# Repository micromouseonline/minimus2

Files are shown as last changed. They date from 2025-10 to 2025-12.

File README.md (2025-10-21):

# MINIMUS-2
A half size micromouse design.

## Intent

Create hardware and software for a half-size micromouse robot. The design should be simple and easy to reproduce. It is not necessarily meant to compete at the highest levels. Rather, it should provide a working platform for beginners while still forming the basis for more performant derivatives.

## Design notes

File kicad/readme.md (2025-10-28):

# KiCAD design files for Minimus

All ECAD work is done wih KiCad V8.0

## Libraries

 - Add the JLCPCB parts library by following the instructions here:
    https://github.com/CDFER/JLCPCB-Kicad-Library

    This library contains all the basic parts avaiable from the JLCPCB assembly service, inclluding their footprints and part references.

    As far as I know, the library source is updated every day but the local copy is not so all parts should be checked at the time of a request for manufacture.

    Updates can be done manually from the Plugin manager.

    Since the library is a git repository, it might be possible to clone or fork it, create a local branch and edit the footprints that way.

 - There will also be a custom project library for the parts used in minimus.

## Plugins

 - Add the KiCAD JLC PCB Tools by following the instructions here
     https://github.com/Bouni/kicad-jlcpcb-tools

## Schematic Style

Note that the symbols used by the JLCPCB parts library do not match the symbols that are the default in KiCAD supplied libraries. The most important attributes are all those relating specifically to the JLCPCB part - size, part number, type and so on. If the symbols are a problem, it might be best to copy each part from the JLCPCB library to the project library and edit the symbol there.

## PCB Style

For a half-size mouse, all the components are small and contained in a small PCB. It is not practical to have the component reference and value for all parts. If the boards are to be manufacured by a service, this is not a great problem. A reference diagram showing the part placement from the FAB layers would be helpful for testing and debugging.

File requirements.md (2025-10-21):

# MINIMUS-2
A half size micromouse design.

## Intent

Create hardware and software for a half-size micromouse robot. The design should be simple and easy to reproduce. It is not necessarily meant to compete at the highest levels. Rather, it should provide a working platform for beginners while still forming the basis for more performant derivatives.

As with many of my projects, a key aim is to lay the foundation for a competitive robot in the future and so there seems little point in overly constraining the design.

### Mechanical

 1. The chassis will be based on the PCB which will be 0.8mm FR4. 
 1. Dimensions should not exceed 50mm x 40mm.
 1. Motor mounts will be 3D printed. Ideally using SLA (resin) techniques though FDM should be an option.
 1. The differential drive will be by means of two wheels to leave space for a suction fan
 1. The initial design will not incorporate a fan but allowance should be made at all times for the possibility of adding a fan at a later date.
 1. Motors will be commonly available 6x12mm coreless types.
 1. Gears are readily available as 8+54 tooth 0.3mod pairs intended for small drones. That leaves the wheels larger than ideal (> 18mm diameter). A tradeoff for availability.
 1. Wheels will need to be SLA printed to engage with available drive gears.
 1. Tyres could be deNano types but o-rings or similar are likely to prove suitable at this stage.

### Sensors

 1. Wall sensors will use four pairs of IR or visible light reflective devices. Emitters may need to be 5mm diameter though 3mm types are to be preferred. Narrow beam emitters are coupled with detectors having a wider acceptance angle.  These whould be as simple as possible.
 1. An IMU having at least 6 axes (3*gyro + 3*accel) will provide feedback for rotational motion. The accelerometers may prove necessary for velocity estimation, crash detection and user input.
 1. Wheel encoders are the promary inputs for linear odometry and also make useful user input devices. High resolution magentic angle sensors may be fitted to the main wheels with the sensor carriers vertical on the PCB behind the motor mounts. Magnetic shielding for the motors may be needed. Lower resolution encoders 1. possibly optical 1. may be effective if used with the IMU.
  
### User IO

 1. There should be at least one user button in addition to the processor reset. This button may also be used to place the processor into bootloader mode at power up if necessary/appropriate. The ESP32 processor are likely to need this.
 1. All otherwise unused pins should have LEDs attached for state and/or operating mode indication. Neopixel devices are useful if there is support available. If space permits, an I2C LED driver might be an option.
 1. Debug (SWD) and serial connections are essential during development. These must be reliable but have low insertion force and relatively long cycle life.
 1. A small buzzer is often useful if space permits.
 1. A pluggable display would be a great addition. Conceivably it could be a pass-through for the debug/programming connector.
 1. A radio link might be substituted for a display. Perhaps all these could be stacked for development and removed for contest runs.

### Electrical

 1. Power should come from 1 or 2 LiPo cells. A single cell might be sufficient but it is best to allow for more in the design. Space must be left for two cells in the mechanical layout.
 1. Care must be taken to find suitable cells that are likely to have a long availability.
 1. Cells should have individual connectors for greatest flexibility.
 1. Connectors are likely to need modification for low insertion force as cycle life is often low.
 1. Try to find commonly used connectors such as those used in micro drones. These are very fiddly to make by hand. Prefer ready-made.
 1. Run times can be long so cell capacity will need careful consideration.
 1. Power switching will need a mechanical switch and high-side MOSFET as suitably sized switches do not have sufficient current carrying capacity.

### Processor

 1. A 32 bit processor seems inevitable. It should run C++ code and, for those who must, MicroPython.
 1. Emphasis should be given to maximising available RAM and the availability of non-volatile storage. 
 1. Flash sizes should exceed 512K for flexibility.
 1. At least one SPI and one I2C peripheral will be needed to accomodate the IMU
 1. Ideally, two hardware quadrature input channels will be available or should be possible using interrupts. If the same pins can be used for SPI, in addition to the IMU, then that would provide greater flexibility in the choice of encoder topology. Note that some optical encoder designs might need analogue inputs.
 1. There should be a suitable debug interface that will work with commonly available tools like openOCD.
 1. For power saving, it should be possible to activate a low power or standby mode. This may be as simple as reducing the processor clock.
 1. It would be most convenient, for C+++ development, if the processor is supported by PlatformIO. Like it or not, this provides a great deal of flexibility. Not least in the choice of available development environments across platforms.
 1. Support for the Arduino framework, while not giving the highest performance, would greatly simplify the portability of the code.
 1. Early adoption of an RTOS might bring benefits. It is automatically available for the ESP32 and easy to implement for the STM32
 1. Processor choice seems likely to be between STM32F413 and ESP32. Both provide all the required features. Ready built breakout boards are unusally rare in this size. STM32F413RGT and ESP32-PICO placed directly on the board are the most space efficient. ESP32 modules can be compact and provide wireless links but are still quite large and may mean a dual board configuration. Of course, with care, the entire processor could be on a (probably custom) carrier.
  
### Assembly

 1. Given the size of the robot, it is going to require SMT devices. Some of these are hard to mount without some experience. IMUs and motor drivers in particular are usually tiny, leadless devices. It should be assumed that boards will be pre-assembled by services such as PCBWAY or JLCPCB. The higher cost is likely to be easily offset by improved reliability, reduced frustration and the removal of a requirement to hold stocks of components locally.
 2. A pre-assembled board should maximise the cost benefits by having as much circuitry as possible mounted at manufacture. That includes encoders and, if appropriate, sensor carriers with all but the optical devices already mounted. 
 3. It may be a good idea to include chargers and/or serial interface options at the same time.
 4. Groups purchases are probably the way to go.
 5. Fasteners must be readily avaiable and robust.
 6. Bearings, axles and retainers can be a challenge. All must be readily available with little or no modification. For example, axle shafts will ideally be available in the right length without cutting. Good push fits can be surprisingly effective at these scales.

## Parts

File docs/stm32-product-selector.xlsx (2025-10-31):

Microcontrollers & microprocessors/STM32 32-bit Arm Cortex MCUs
Part Number | General Description | Marketing Status | USART typ | UART Total | UART typ | Timers (32-bit) typ | Timers (16-bit) typ | SPI Total | SPI typ | Package Pin Count | I2C Total | I2C typ | FPU | Data E2PROM (B) nom | CCM RAM (I/D) (kByte) typ | Advanced Motor Control Timers | Additional Interfaces | A/D Converters 16-bit |  | A/D Converters 14-bit | A/D Converters 12-bit | A/D Converters 14-bit | A/D Converters 12-bit | Package | Core | Operating Frequency (MHz) | Flash Size (kB) (Prog) | RAM Size (kB) | I/Os (High Current) | GP Timers Total | A/D Converters: Total Number of A/D Converters
 |  |  |  |  |  |  |  |  |  |  |  |  |  |  |  |  |  | Number of Channels typ | Number of A/D Converters typ | Number of Channels typ | Number of Channels typ | Number of A/D Converters typ | Number of A/D Converters typ
STM32L4Q5RGT6P (https://www.st.com/en/product/stm32l4q5rgt6p.html) | Ultra-low-power with FPU Arm Cortex-M4 MCU 120 MHz with 1024 kbytes of Flash memory, USB OTG, DFSDM, CHROM-ART, AES, PKA | Active | - | 1 | - | 2 | 11 | - | - | 64 | 4 | 4 | Single-precision FPU | - | - | - | DFSDM, SAI | - | - | - | - | - | 2 | LQFP 64 10x10x1.4 mm | Arm Cortex-M4 | 120 | 1024 | 320 | - | 13 | 2
STM32L4Q5RGT3 (https://www.st.com/en/product/stm32l4q5rgt3.html) | Ultra-low-power with FPU Arm Cortex-M4 MCU 120 MHz with 1024 kbytes of Flash memory, USB OTG, DFSDM, CHROM-ART, AES, PKA | Active | 6 | 7 | - | 2 | 11 | 9 | 3 | 64 | 4 | 4 | Single-precision FPU | - | - | - | DFSDM, SAI | - | - | - | 16 | - | 2 | LQFP 64 10x10x1.4 mm | Arm Cortex-M4 | 120 | 1024 | 320 | 54 | 13 | 2
STM32L4Q5RGT6 (https://www.st.com/en/product/stm32l4q5rgt6.html) | Ultra-low-power with FPU Arm Cortex-M4 MCU 120 MHz with 1024 kbytes of Flash memory, USB OTG, DFSDM, CHROM-ART, AES, PKA | Active | 6 | 7 | - | 2 | 11 | 9 | 3 | 64 | 4 | 4 | Single-precision FPU | - | - | - | DFSDM, SAI | - | - | - | 16 | - | 2 | LQFP 64 10x10x1.4 mm | Arm Cortex-M4 | 120 | 1024 | 320 | 54 | 13 | 2
STM32L4P5RGT6 (https://www.st.com/en/product/stm32l4p5rgt6.html) | Ultra-low-power with FPU Arm Cortex-M4 MCU 120 MHz with 1024 kbytes of Flash memory, USB OTG, DFSDM, CHROM-ART | Active | - | 1 | - | 2 | 11 | - | - | 64 | 4 | 4 | Single-precision FPU | - | - | - | DFSDM, SAI | - | - | - | - | - | 2 | LQFP 64 10x10x1.4 mm | Arm Cortex-M4 | 120 | 1024 | 320 | 54 | 13 | 2
STM32L4P5RGT6P (https://www.st.com/en/product/stm32l4p5rgt6p.html) | Ultra-low-power with FPU Arm Cortex-M4 MCU 120 MHz with 1024 kbytes of Flash memory, USB OTG, DFSDM, CHROM-ART | Active | - | 1 | - | 2 | 11 | - | - | 64 | 4 | 4 | Single-precision FPU | - | - | - | DFSDM, SAI | - | - | - | - | - | 2 | LQFP 64 10x10x1.4 mm | Arm Cortex-M4 | 120 | 1024 | 320 | 54 | 13 | 2
STM32U595RIT6QTR (https://www.st.com/en/product/stm32u595rit6qtr.html) | Ultra-low-power with FPU Arm Cortex-M33 MCU with TrustZone, 160 MHz with 2 Mbytes of Flash memory | Active | 4 | 8 | 3 | 4 | 11 | 7 | 3 | 64 | 6 | 6 | Single-precision FPU | - | - | - | - | - | - | 15 | 15 | 2 | 1 | LQFP 64 10x10x1.4 mm | Arm Cortex-M33 | 160 | 2048 | 2514 | 47 | 15 | 3
STM32U595RIT6Q (https://www.st.com/en/product/stm32u595rit6q.html) | Ultra-low-power with FPU Arm Cortex-M33 MCU with TrustZone, 160 MHz with 2 Mbytes of Flash memory | Active | 4 | 8 | 3 | 4 | 11 | 7 | 3 | 64 | 6 | 6 | Single-precision FPU | - | - | - | - | - | - | 15 | 15 | 2 | 1 | LQFP 64 10x10x1.4 mm | Arm Cortex-M33 | 160 | 2048 | 2514 | 47 | 15 | 3
STM32U595RIT6TR (https://www.st.com/en/product/stm32u595rit6tr.html) | Ultra-low-power with FPU Arm Cortex-M33 MCU with TrustZone, 160 MHz with 2 Mbytes of Flash memory | Active | 4 | 8 | 3 | 4 | 11 | 7 | 3 | 64 | 6 | 6 | Single-precision FPU | - | - | - | - | - | - | 17 | 17 | 2 | 1 | LQFP 64 10x10x1.4 mm | Arm Cortex-M33 | 160 | 2048 | 2514 | 51 | 15 | 3
STM32U595RIT6 (https://www.st.com/en/product/stm32u595rit6.html) | Ultra-low-power with FPU Arm Cortex-M33 MCU with TrustZone, 160 MHz with 2 Mbytes of Flash memory | Active | 4 | 8 | 3 | 4 | 11 | 7 | 3 | 64 | 6 | 6 | Single-precision FPU | - | - | - | - | - | - | 17 | 17 | 2 | 1 | LQFP 64 10x10x1.4 mm | Arm Cortex-M33 | 160 | 2048 | 2514 | 51 | 15 | 3
STM32U595RJT6 (https://www.st.com/en/product/stm32u595rjt6.html) | Ultra-low-power with FPU Arm Cortex-M33 MCU with TrustZone, 160 MHz with 4 Mbytes of Flash memory | Active | 4 | 8 | 3 | 4 | 11 | 7 | 3 | 64 | 6 | 6 | Single-precision FPU | - | - | - | - | - | - | 17 | 17 | 2 | 1 | LQFP 64 10x10x1.4 mm | Arm Cortex-M33 | 160 | 4096 | 2514 | 51 | 15 | 3
STM32U595RJT3 (https://www.st.com/en/product/stm32u595rjt3.html) | Ultra-low-power with FPU Arm Cortex-M33 MCU with TrustZone, 160 MHz with 4 Mbytes of Flash memory | Active | 4 | 8 | 3 | 4 | 11 | 7 | 3 | 64 | 6 | 6 | Single-precision FPU | - | - | - | - | - | - | 17 | 17 | 2 | 1 | LQFP 64 10x10x1.4 mm | Arm Cortex-M33 | 160 | 4096 | 2514 | 51 | 15 | 3
STM32U595RJT6Q (https://www.st.com/en/product/stm32u595rjt6q.html) | Ultra-low-power with FPU Arm Cortex-M33 MCU with TrustZone, 160 MHz with 4 Mbytes of Flash memory | Active | 4 | 8 | 3 | 4 | 11 | 7 | 3 | 64 | 6 | 6 | Single-precision FPU | - | - | - | - | - | - | 15 | 15 | 2 | 1 | LQFP 64 10x10x1.4 mm | Arm Cortex-M33 | 160 | 4096 | 2514 | 47 | 15 | 3
STM32U5A5RJT6 (https://www.st.com/en/product/stm32u5a5rjt6.html) | Ultra-low-power with FPU Arm Cortex-M33 MCU with TrustZone, 160 MHz with 4 Mbytes of Flash memory | Active | 4 | 8 | 3 | 4 | 11 | 7 | 3 | 64 | 6 | 6 | Single-precision FPU | - | - | - | - | - | - | 17 | 17 | 2 | 1 | LQFP 64 10x10x1.4 mm | Arm Cortex-M33 | 160 | 4096 | 2514 | 51 | 15 | 3
STM32U5A5RJT6Q (https://www.st.com/en/product/stm32u5a5rjt6q.html) | Ultra-low-power with FPU Arm Cortex-M33 MCU with TrustZone, 160 MHz with 4 Mbytes of Flash memory | Active | 4 | 8 | 3 | 4 | 11 | 7 | 3 | 64 | 6 | 6 | Single-precision FPU | - | - | - | - | - | - | 15 | 15 | 2 | 1 | LQFP 64 10x10x1.4 mm | Arm Cortex-M33 | 160 | 4096 | 2514 | 47 | 15 | 3
STM32U575RGT6TR (https://www.st.com/en/product/stm32u575rgt6tr.html) | Ultra-low-power with FPU Arm Cortex-M33 MCU with TrustZone, 160 MHz with 1 Mbyte of Flash memory | Active | 3 | 6 | 2 | - | - | 6 | 3 | 64 | 4 | 4 | Single-precision FPU | - | - | - | ADF, MDF, Parallel camera interface, SAI, SD/MMC, Vref Buffer | - | - | 17 | 17 | 1 | 1 | LQFP 64 10x10x1.4 mm | Arm Cortex-M33 | 160 | 1024 | 786 | 50 | - | 2
STM32U575RGT6QTR (https://www.st.com/en/product/stm32u575rgt6qtr.html) | Ultra-low-power with FPU Arm Cortex-M33 MCU with TrustZone, 160 MHz with 1 Mbyte of Flash memory | Active | 3 | 6 | 2 | - | - | 6 | 3 | 64 | 4 | 4 | Single-precision FPU | - | - | - | ADF, MDF, Parallel camera interface, SAI, SD/MMC, Vref Buffer | - | - | 15 | 15 | 1 | 1 | LQFP 64 10x10x1.4 mm | Arm Cortex-M33 | 160 | 1024 | 786 | 47 | - | 2
STM32U575RGT3 (https://www.st.com/en/product/stm32u575rgt3.html) | Ultra-low-power with FPU Arm Cortex-M33 MCU with TrustZone, 160 MHz with 1 Mbyte of Flash memory | Active | 3 | 6 | 2 | - | - | 6 | 3 | 64 | 4 | 4 | Single-precision FPU | - | - | - | ADF, MDF, Parallel camera interface, SAI, SD/MMC, Vref Buffer | - | - | 17 | 17 | 1 | 1 | LQFP 64 10x10x1.4 mm | Arm Cortex-M33 | 160 | 1024 | 786 | 50 | - | 2
STM32U575RGT6 (https://www.st.com/en/product/stm32u575rgt6.html) | Ultra-low-power with FPU Arm Cortex-M33 MCU with TrustZone, 160 MHz with 1 Mbyte of Flash memory | Active | 3 | 6 | 2 | - | - | 6 | 3 | 64 | 4 | 4 | Single-precision FPU | - | - | - | ADF, MDF, Parallel camera interface, SAI, SD/MMC, Vref Buffer | - | - | 17 | 17 | 1 | 1 | LQFP 64 10x10x1.4 mm | Arm Cortex-M33 | 160 | 1024 | 786 | 50 | - | 2
STM32U575RGT6Q (https://www.st.com/en/product/stm32u575rgt6q.html) | Ultra-low-power with FPU Arm Cortex-M33 MCU with TrustZone, 160 MHz with 1 Mbyte of Flash memory | Active | 3 | 6 | 2 | - | - | 6 | 3 | 64 | 4 | 4 | Single-precision FPU | - | - | - | ADF, MDF, Parallel camera interface, SAI, SD/MMC, Vref Buffer | - | - | 15 | 15 | 1 | 1 | LQFP 64 10x10x1.4 mm | Arm Cortex-M33 | 160 | 1024 | 786 | 47 | - | 2
STM32U575RIT3 (https://www.st.com/en/product/stm32u575rit3.html) | Ultra-low-power with FPU Arm Cortex-M33 MCU with TrustZone, 160 MHz with 2 Mbytes of Flash memory | Active | 3 | 6 | 2 | - | - | 6 | 3 | 64 | 4 | 4 | Single-precision FPU | - | - | - | ADF, MDF, Parallel camera interface, SAI, SD/MMC | - | - | 17 | 17 | 1 | 1 | LQFP 64 10x10x1.4 mm | Arm Cortex-M33 | 160 | 2048 | 786 | 50 | - | 2
STM32U575RIT6Q (https://www.st.com/en/product/stm32u575rit6q.html) | Ultra-low-power with FPU Arm Cortex-M33 MCU with TrustZone, 160 MHz with 2 Mbytes of Flash memory | Active | 3 | 6 | 2 | - | - | 6 | 3 | 64 | 4 | 4 | Single-precision FPU | - | - | - | ADF, MDF, Parallel camera interface, SAI, SD/MMC | - | - | 15 | 15 | 1 | 1 | LQFP 64 10x10x1.4 mm | Arm Cortex-M33 | 160 | 2048 | 786 | 47 | - | 2
STM32U575RIT6 (https://www.st.com/en/product/stm32u575rit6.html) | Ultra-low-power with FPU Arm Cortex-M33 MCU with TrustZone, 160 MHz with 2 Mbytes of Flash memory | Active | 3 | 6 | 2 | - | - | 6 | 3 | 64 | 4 | 4 | Single-precision FPU | - | - | - | ADF, MDF, Parallel camera interface, SAI, SD/MMC | - | - | 17 | 17 | 1 | 1 | LQFP 64 10x10x1.4 mm | Arm Cortex-M33 | 160 | 2048 | 786 | 50 | - | 2
STM32U585RIT3TR (https://www.st.com/en/product/stm32u585rit3tr.html) | Ultra-low-power with FPU Arm Cortex-M33 MCU with TrustZone, 160 MHz with 2 Mbytes of Flash memory | Active | 3 | 6 | 2 | - | - | 6 | 3 | 64 | 4 | 4 | Single-precision FPU | - | - | - | ADF, MDF, Parallel camera interface, SAI, SD/MMC | - | - | 17 | 17 | 1 | 1 | LQFP 64 10x10x1.4 mm | Arm Cortex-M33 | 160 | 2048 | 786 | 50 | - | 2
STM32U585RIT6 (https://www.st.com/en/product/stm32u585rit6.html) | Ultra-low-power with FPU Arm Cortex-M33 MCU with TrustZone, 160 MHz with 2 Mbytes of Flash memory | Active | 3 | 6 | 2 | - | - | 6 | 3 | 64 | 4 | 4 | Single-precision FPU | - | - | - | ADF, MDF, Parallel camera interface, SAI, SD/MMC | - | - | 17 | 17 | 1 | 1 | LQFP 64 10x10x1.4 mm | Arm Cortex-M33 | 160 | 2048 | 786 | 50 | - | 2
STM32U585RIT6QTR (https://www.st.com/en/product/stm32u585rit6qtr.html) | Ultra-low-power with FPU Arm Cortex-M33 MCU with TrustZone, 160 MHz with 2 Mbytes of Flash memory | Active | 3 | 6 | 2 | - | - | 6 | 3 | 64 | 4 | 4 | Single-precision FPU | - | - | - | ADF, MDF, Parallel camera interface, SAI, SD/MMC | - | - | 15 | 15 | 1 | 1 | LQFP 64 10x10x1.4 mm | Arm Cortex-M33 | 160 | 2048 | 786 | 47 | - | 2
STM32U585RIT6Q (https://www.st.com/en/product/stm32u585rit6q.html) | Ultra-low-power with FPU Arm Cortex-M33 MCU with TrustZone, 160 MHz with 2 Mbytes of Flash memory | Active | 3 | 6 | 2 | - | - | 6 | 3 | 64 | 4 | 4 | Single-precision FPU | - | - | - | ADF, MDF, Parallel camera interface, SAI, SD/MMC | - | - | 15 | 15 | 1 | 1 | LQFP 64 10x10x1.4 mm | Arm Cortex-M33 | 160 | 2048 | 786 | 47 | - | 2
STM32U585RIT6TR (https://www.st.com/en/product/stm32u585rit6tr.html) | Ultra-low-power with FPU Arm Cortex-M33 MCU with TrustZone, 160 MHz with 2 Mbytes of Flash memory | Active | 3 | 6 | 2 | - | - | 6 | 3 | 64 | 4 | 4 | Single-precision FPU | - | - | - | ADF, MDF, Parallel camera interface, SAI, SD/MMC | - | - | 17 | 17 | 1 | 1 | LQFP 64 10x10x1.4 mm | Arm Cortex-M33 | 160 | 2048 | 786 | 50 | - | 2
STM32U585RIT3Q (https://www.st.com/en/product/stm32u585rit3q.html) | Ultra-low-power with FPU Arm Cortex-M33 MCU with TrustZone, 160 MHz with 2 Mbytes of Flash memory | Active | 3 | 6 | 2 | 4 | 11 | 6 | 3 | 64 | 4 | 4 | Single-precision FPU | - | - | 2 | ADF, MDF, Parallel camera interface, SAI, SD/MMC | - | - | 15 | 15 | 1 | 1 | LQFP 64 10x10x1.4 mm | Arm Cortex-M33 | 160 | 2048 | 786 | 47 | 15 | 2
STM32U585RIT3 (https://www.st.com/en/product/stm32u585rit3.html) | Ultra-low-power with FPU Arm Cortex-M33 MCU with TrustZone, 160 MHz with 2 Mbytes of Flash memory | Active | 3 | 6 | 2 | - | - | 6 | 3 | 64 | 4 | 4 | Single-precision FPU | - | - | - | ADF, MDF, Parallel camera interface, SAI, SD/MMC | - | - | 17 | 17 | 1 | 1 | LQFP 64 10x10x1.4 mm | Arm Cortex-M33 | 160 | 2048 | 786 | 50 | - | 2
STM32L4A6RGT6P (https://www.st.com/en/product/stm32l4a6rgt6p.html) | Ultra-low-power with FPU Arm Cortex-M4 MCU 80 MHz with 1 Mbyte of Flash memory, USB OTG, LCD, AES-256, DFSDM | Active | 3 | 6 | 2 | 2 | 9 | 6 | 3 | 64 | 3 | 3 | Single-precision FPU | - | - | - | DFSDM, Parallel camera interface, SAI, SD/MMC | - | - | - | 15 | - | 3 | LQFP 64 10x10x1.4 mm | Arm Cortex-M4 | 80 | 1024 | 320 | 50 | 11 | 3
STM32L4A6RGT6TR (https://www.st.com/en/product/stm32l4a6rgt6tr.html) | Ultra-low-power with FPU Arm Cortex-M4 MCU 80 MHz with 1 Mbyte of Flash memory, USB OTG, LCD, AES-256, DFSDM | Active | 3 | 6 | 2 | 2 | 9 | 6 | 3 | 64 | 3 | 3 | Single-precision FPU | - | - | - | DFSDM, Parallel camera interface, SAI, SD/MMC | - | - | - | 16 | - | 3 | LQFP 64 10x10x1.4 mm | Arm Cortex-M4 | 80 | 1024 | 320 | 52 | 11 | 3
STM32L4A6RGT7 (https://www.st.com/en/product/stm32l4a6rgt7.html) | Ultra-low-power with FPU Arm Cortex-M4 MCU 80 MHz with 1 Mbyte of Flash memory, USB OTG, LCD, AES-256, DFSDM | Active | 3 | 6 | 2 | 2 | 9 | 6 | 3 | 64 | 3 | 3 | Single-precision FPU | - | - | - | DFSDM, Parallel camera interface, SAI, SD/MMC | - | - | - | 16 | - | 3 | LQFP 64 10x10x1.4 mm | Arm Cortex-M4 | 80 | 1024 | 320 | 52 | 11 | 3
STM32L4A6RGT6 (https://www.st.com/en/product/stm32l4a6rgt6.html) | Ultra-low-power with FPU Arm Cortex-M4 MCU 80 MHz with 1 Mbyte of Flash memory, USB OTG, LCD, AES-256, DFSDM | Active | 3 | 6 | 2 | 2 | 9 | 6 | 3 | 64 | 3 | 3 | Single-precision FPU | - | - | - | DFSDM, Parallel camera interface, SAI, SD/MMC | - | - | - | 16 | - | 3 | LQFP 64 10x10x1.4 mm | Arm Cortex-M4 | 80 | 1024 | 320 | 52 | 11 | 3
STM32L4A6RGT7TR (https://www.st.com/en/product/stm32l4a6rgt7tr.html) | Ultra-low-power with FPU Arm Cortex-M4 MCU 80 MHz with 1 Mbyte of Flash memory, USB OTG, LCD, AES-256, DFSDM | Active | 3 | 6 | 2 | 2 | 9 | 6 | 3 | 64 | 3 | 3 | Single-precision FPU | - | - | - | DFSDM, Parallel camera interface, SAI, SD/MMC | - | - | - | 16 | - | 3 | LQFP 64 10x10x1.4 mm | Arm Cortex-M4 | 80 | 1024 | 320 | 52 | 11 | 3
STM32L496RGT6TR (https://www.st.com/en/product/stm32l496rgt6tr.html) | Ultra-low-power with FPU Arm Cortex-M4 MCU 80 MHz with 1 Mbyte of Flash memory, USB OTG, LCD, DFSDM | Active | 3 | 6 | 2 | 2 | 9 | 6 | 3 | 64 | - | - | Single-precision FPU | - | - | - | DFSDM, Parallel camera interface, SAI, SD/MMC | - | - | - | 16 | - | 3 | LQFP 64 10x10x1.4 mm | Arm Cortex-M4 | 80 | 1024 | 320 | 52 | 11 | 3
STM32L496RGT3 (https://www.st.com/en/product/stm32l496rgt3.html) | Ultra-low-power with FPU Arm Cortex-M4 MCU 80 MHz with 1 Mbyte of Flash memory, USB OTG, LCD, DFSDM | Active | 3 | 6 | 2 | 2 | 9 | 6 | 3 | 64 | - | - | Single-precision FPU | - | - | - | DFSDM, Parallel camera interface, SAI, SD/MMC | - | - | - | 16 | - | 3 | LQFP 64 10x10x1.4 mm | Arm Cortex-M4 | 80 | 1024 | 320 | 52 | 11 | 3
STM32L496RGT6P (https://www.st.com/en/product/stm32l496rgt6p.html) | Ultra-low-power with FPU Arm Cortex-M4 MCU 80 MHz with 1 Mbyte of Flash memory, USB OTG, LCD, DFSDM | Active | 3 | 6 | 2 | 2 | 9 | 6 | 3 | 64 | - | - | Single-precision FPU | - | - | - | DFSDM, Parallel camera interface, SAI, SD/MMC | - | - | - | 15 | - | 3 | LQFP 64 10x10x1.4 mm | Arm Cortex-M4 | 80 | 1024 | 320 | 50 | 11 | 3
STM32L496RGT3TR (https://www.st.com/en/product/stm32l496rgt3tr.html) | Ultra-low-power with FPU Arm Cortex-M4 MCU 80 MHz with 1 Mbyte of Flash memory, USB OTG, LCD, DFSDM | Active | 3 | 6 | 2 | 2 | 9 | 6 | 3 | 64 | - | - | Single-precision FPU | - | - | - | DFSDM, Parallel camera interface, SAI, SD/MMC | - | - | - | 16 | - | 3 | LQFP 64 10x10x1.4 mm | Arm Cortex-M4 | 80 | 1024 | 320 | 52 | 11 | 3
STM32L496RGT6 (https://www.st.com/en/product/stm32l496rgt6.html) | Ultra-low-power with FPU Arm Cortex-M4 MCU 80 MHz with 1 Mbyte of Flash memory, USB OTG, LCD, DFSDM | Active | 3 | 6 | 2 | 2 | 9 | 6 | 3 | 64 | - | - | Single-precision FPU | - | - | - | DFSDM, Parallel camera interface, SAI, SD/MMC | - | - | - | 16 | - | 3 | LQFP 64 10x10x1.4 mm | Arm Cortex-M4 | 80 | 1024 | 320 | 52 | 11 | 3
STM32F423RHT6TR (https://www.st.com/en/product/stm32f423rht6tr.html) | High-performance access line, Arm Cortex-M4 core with DSP and FPU, 1, 5 MByte of Flash memory, 100 MHz CPU, ART Accelerator, DFSDM, AES | Active | 4 | 7 | 3 | 2 | 12 | 9 | 5 | 64 | 4 | 3 | - | - | - | - | DFSDM, SAI, SD/MMC | - | - | - | 16 | - | 1 | LQFP 64 10x10x1.4 mm | Arm Cortex-M4 | 100 | 1536 | 320 | 50 | 14 | 1
STM32F423RHT6 (https://www.st.com/en/product/stm32f423rht6.html) | High-performance access line, Arm Cortex-M4 core with DSP and FPU, 1, 5 MByte of Flash memory, 100 MHz CPU, ART Accelerator, DFSDM, AES | Active | 4 | 7 | 3 | 2 | 12 | 9 | 5 | 64 | 4 | 3 | - | - | - | - | DFSDM, SAI, SD/MMC | - | - | - | 16 | - | 1 | LQFP 64 10x10x1.4 mm | Arm Cortex-M4 | 100 | 1536 | 320 | 50 | 14 | 1
STM32F413RHT6TR (https://www.st.com/en/product/stm32f413rht6tr.html) | High-performance access line, Arm Cortex-M4 core with DSP and FPU, 1, 5 MByte of Flash memory, 100 MHz CPU, ART Accelerator, DFSDM | Active | 4 | 7 | 3 | 2 | 12 | 9 | 5 | 64 | 4 | 3 | - | - | - | - | DFSDM, SAI, SD/MMC | - | - | - | 16 | - | 1 | LQFP 64 10x10x1.4 mm | Arm Cortex-M4 | 100 | 1536 | 320 | 50 | 14 | 1
STM32F413RHT6 (https://www.st.com/en/product/stm32f413rht6.html) | High-performance access line, Arm Cortex-M4 core with DSP and FPU, 1, 5 MByte of Flash memory, 100 MHz CPU, ART Accelerator, DFSDM | Active | 4 | 7 | 3 | 2 | 12 | 9 | 5 | 64 | 4 | 3 | - | - | - | - | DFSDM, SAI, SD/MMC | - | - | - | 16 | - | 1 | LQFP 64 10x10x1.4 mm | Arm Cortex-M4 | 100 | 1536 | 320 | 50 | 14 | 1
STM32F413RHT3 (https://www.st.com/en/product/stm32f413rht3.html) | High-performance access line, Arm Cortex-M4 core with DSP and FPU, 1, 5 MByte of Flash memory, 100 MHz CPU, ART Accelerator, DFSDM | Active | 4 | 7 | 3 | 2 | 12 | 9 | 5 | 64 | 4 | 3 | - | - | - | - | DFSDM, SAI, SD/MMC | - | - | - | 16 | - | 1 | LQFP 64 10x10x1.4 mm | Arm Cortex-M4 | 100 | 1536 | 320 | 50 | 14 | 1
STM32F413RGT6 (https://www.st.com/en/product/stm32f413rgt6.html) | High-performance access line, Arm Cortex-M4 core with DSP and FPU, 1 MByte of Flash memory, 100 MHz CPU, ART Accelerator, DFSDM | Active | 4 | 7 | 3 | 2 | 12 | 9 | 5 | 64 | 4 | 3 | - | - | - | - | DFSDM, SAI, SD/MMC | - | - | - | 16 | - | 1 | LQFP 64 10x10x1.4 mm | Arm Cortex-M4 | 100 | 1024 | 320 | 50 | 14 | 1
STM32F413RGT6TR (https://www.st.com/en/product/stm32f413rgt6tr.html) | High-performance access line, Arm Cortex-M4 core with DSP and FPU, 1 MByte of Flash memory, 100 MHz CPU, ART Accelerator, DFSDM | Active | 4 | 7 | 3 | 2 | 12 | 9 | 5 | 64 | 4 | 3 | - | - | - | - | DFSDM, SAI, SD/MMC | - | - | - | 16 | - | 1 | LQFP 64 10x10x1.4 mm | Arm Cortex-M4 | 100 | 1024 | 320 | 50 | 14 | 1
STM32H7A3RIT6 (https://www.st.com/en/product/stm32h7a3rit6.html) | High-performance and DSP with DP-FPU, Arm Cortex-M7 MCU with 2MBytes of Flash memory, 1376 KB SRAM, 280 MHz CPU, L1 cache, graphic accelerations, extenal memory interfaces and large set of peripherals | Active | - | 1 | - | - | - | - | - | 64 | 3 | 3 | - | - | - | - | DFSDM, HDMI CEC, Parallel camera interface, S/PDIF, SAI, SD/MMC | - | - | - | - | - | - | LQFP 64 10x10x1.4 mm | Arm Cortex-M7 | 280 | 2048 | 1184 | 49 | - | -
STM32H7A3RIT6TR (https://www.st.com/en/product/stm32h7a3rit6tr.html) | High-performance and DSP with DP-FPU, Arm Cortex-M7 MCU with 2MBytes of Flash memory, 1376 KB SRAM, 280 MHz CPU, L1 cache, graphic accelerations, extenal memory interfaces and large set of peripherals | Active | - | 1 | - | - | - | - | - | 64 | 3 | 3 | - | - | - | - | DFSDM, HDMI CEC, Parallel camera interface, S/PDIF, SAI, SD/MMC | - | - | - | - | - | - | LQFP 64 10x10x1.4 mm | Arm Cortex-M7 | 280 | 2048 | 1184 | 49 | - | -
STM32H7A3RGT6 (https://www.st.com/en/product/stm32h7a3rgt6.html) | High-performance and DSP with DP-FPU, Arm Cortex-M7 MCU with 1MBytes of Flash memory, 1376 KB SRAM, 280 MHz CPU, L1 cache, graphic accelerations, extenal memory interfaces and large set of peripherals | Active | - | 1 | - | - | - | - | - | 64 | 3 | 3 | - | - | - | - | DFSDM, HDMI CEC, Parallel camera interface, S/PDIF, SAI, SD/MMC | - | - | - | - | - | - | LQFP 64 10x10x1.4 mm | Arm Cortex-M7 | 280 | 1024 | 1184 | 49 | - | -
STM32H7B3RIT6 (https://www.st.com/en/product/stm32h7b3rit6.html) | High-performance and DSP with DP-FPU, Arm Cortex-M7 MCU with 2MBytes of Flash memory, 1376 KB SRAM, 280 MHz CPU, L1 cache, graphic accelerations, extenal memory interfaces and large set of peripherals | Active | - | 1 | - | - | - | - | - | 64 | 3 | 3 | - | - | - | - | DFSDM, HDMI CEC, Parallel camera interface, S/PDIF, SAI, SD/MMC | - | - | - | - | - | - | LQFP 64 10x10x1.4 mm | Arm Cortex-M7 | 280 | 2048 | 1184 | 49 | - | -
STM32H573RIT6 (https://www.st.com/en/product/stm32h573rit6.html) | High-performance, Arm Cortex-M33 with TrustZone, MCU with 2-Mbyte Flash, 640-Kbyte RAM, 250 MHz CPU | Active | 5 | 12 | 6 | 2 | 16 | 11 | 6 | 64 | 5 | 4 | Single-precision FPU | - | - | 2 | Ethenet, Parallel camera interface, SAI, SD/MMC | - | - | - | 16 | - | 2 | LQFP 64 10x10x1.4 mm | Arm Cortex-M33 | 250 | 2048 | 640 | 53 | 18 | 2
STM32H563RGT6 (https://www.st.com/en/product/stm32h563rgt6.html) | High-performance, Arm Cortex-M33 with TrustZone, MCU with 1-Mbyte Flash, 640-Kbyte RAM, 250 MHz CPU | Active | 5 | 12 | 6 | 2 | 16 | 9 | 4 | 64 | 5 | 4 | Single-precision FPU | - | - | 2 | Ethenet, Parallel camera interface, SAI, SD/MMC | - | - | - | 16 | - | 2 | LQFP 64 10x10x1.4 mm | Arm Cortex-M33 | 250 | 1024 | 640 | 53 | 18 | 2
STM32H563RIT6 (https://www.st.com/en/product/stm32h563rit6.html) | High-performance, Arm Cortex-M33 with TrustZone, MCU with 2-MByte Flash, 640-Kbyte RAM, 250 MHz CPU | Active | 5 | 13 | 7 | 2 | 20 | 9 | 4 | 64 | 5 | 4 | Single-precision FPU | - | - | 2 | Ethenet, Parallel camera interface, SAI, SD/MMC | - | - | - | 16 | - | 2 | LQFP 64 10x10x1.4 mm | Arm Cortex-M33 | 250 | 2048 | 640 | - | 22 | 2
STM32H563RIT7 (https://www.st.com/en/product/stm32h563rit7.html) | High-performance, Arm Cortex-M33 with TrustZone, MCU with 2-MByte Flash, 640-Kbyte RAM, 250 MHz CPU | Active | 5 | 13 | 7 | 2 | 20 | 9 | 4 | 64 | 5 | 4 | Single-precision FPU | - | - | 2 | Ethenet, Parallel camera interface, SAI, SD/MMC | - | - | - | 16 | - | 2 | LQFP 64 10x10x1.4 mm | Arm Cortex-M33 | 250 | 2048 | 640 | - | 22 | 2
STM32H562RGT6 (https://www.st.com/en/product/stm32h562rgt6.html) | High-performance, Arm Cortex-M33 with TrustZone, MCU with 1-MByte Flash, 640-Kbyte RAM, 250 MHz CPU | Active | 5 | 12 | 6 | 2 | 16 | 9 | 4 | 64 | 5 | 4 | Single-precision FPU | - | - | 2 | Parallel camera interface, SAI, SD/MMC | - | - | - | 16 | - | 2 | LQFP 64 10x10x1.4 mm | Arm Cortex-M33 | 250 | 1024 | 640 | 53 | 18 | 2
STM32H562RGT6TR (https://www.st.com/en/product/stm32h562rgt6tr.html) | High-performance, Arm Cortex-M33 with TrustZone, MCU with 1-MByte Flash, 640-Kbyte RAM, 250 MHz CPU | Active | 5 | 12 | 6 | 2 | 16 | 9 | 4 | 64 | 5 | 4 | Single-precision FPU | - | - | 2 | Parallel camera interface, SAI, SD/MMC | - | - | - | 16 | - | 2 | LQFP 64 10x10x1.4 mm | Arm Cortex-M33 | 250 | 1024 | 640 | 53 | 18 | 2
STM32H562RIT6 (https://www.st.com/en/product/stm32h562rit6.html) | High-performance, Arm Cortex-M33 with TrustZone, MCU with 2-Mbyte Flash, 640-Kbyte RAM, 250 MHz CPU | Active | 5 | 12 | 6 | 2 | 16 | 9 | 4 | 64 | 5 | 4 | Single-precision FPU | - | - | 2 | Parallel camera interface, SAI, SD/MMC | - | - | - | 16 | - | 2 | LQFP 64 10x10x1.4 mm | Arm Cortex-M33 | 250 | 2048 | 640 | 53 | 18 | 2
STM32WBA62CIU6TR (https://www.st.com/en/product/stm32wba62ciu6tr.html) | Ultra-low-power, Arm Cortex-M33 TZ MCU 100 MHz with 2 Mbytes of Flash memory, Bluetooth LE 6.0, 802.15.4, Zigbee, Thread | Active | 2 | 6 | 3 | 1 | 5 | 4 | 2 | 48 | 2 | 2 | Single-precision FPU | - | - | 1 | SAI | - | - | - | 8 | - | 1 | UFQFPN 48 7x7x0.55 mm | Arm Cortex-M33 | 100 | 2048 | 512 | 20 | 6 | 1
STM32WBA62CIU6 (https://www.st.com/en/product/stm32wba62ciu6.html) | Ultra-low-power, Arm Cortex-M33 TZ MCU 100 MHz with 2 Mbytes of Flash memory, Bluetooth LE 6.0, 802.15.4, Zigbee, Thread | Active | 2 | 6 | 3 | 1 | 5 | 4 | 2 | 48 | 2 | 2 | Single-precision FPU | - | - | 1 | SAI | - | - | - | 8 | - | 1 | UFQFPN 48 7x7x0.55 mm | Arm Cortex-M33 | 100 | 2048 | 512 | 20 | 6 | 1
STM32WBA64CIU7 (https://www.st.com/en/product/stm32wba64ciu7.html) | Ultra-low-power, Arm Cortex-M33 TZ MCU 100 MHz with 2 Mbytes of Flash memory, Bluetooth LE 6.0, 802.15.4, Zigbee, Thread | Active | 2 | 6 | 3 | 1 | 5 | 4 | 2 | 48 | 2 | 2 | Single-precision FPU | - | - | 1 | SAI | - | - | - | 8 | - | 1 | UFQFPN 48 7x7x0.55 mm | Arm Cortex-M33 | 100 | 2048 | 512 | 20 | 6 | 1
STM32WBA64CIU6 (https://www.st.com/en/product/stm32wba64ciu6.html) | Ultra-low-power, Arm Cortex-M33 TZ MCU 100 MHz with 2 Mbytes of Flash memory, Bluetooth LE 6.0, 802.15.4, Zigbee, Thread | Active | 2 | 6 | 3 | 1 | 5 | 4 | 2 | 48 | 2 | 2 | Single-precision FPU | - | - | 1 | SAI | - | - | - | 8 | - | 1 | UFQFPN 48 7x7x0.55 mm | Arm Cortex-M33 | 100 | 2048 | 512 | 20 | 6 | 1
STM32WBA65CIU6 (https://www.st.com/en/product/stm32wba65ciu6.html) | Ultra-low-power, Arm Cortex-M33 TZ MCU 100 MHz with 2 Mbytes of Flash memory, Bluetooth LE 6.0, 802.15.4, Zigbee, Thread | Active | 2 | 6 | 3 | 1 | 5 | 4 | 2 | 48 | 2 | 2 | Single-precision FPU | - | - | 1 | SAI | - | - | - | 8 | - | 1 | UFQFPN 48 7x7x0.55 mm | Arm Cortex-M33 | 100 | 2048 | 512 | 20 | 6 | 1
STM32WBA65CIU7 (https://www.st.com/en/product/stm32wba65ciu7.html) | Ultra-low-power, Arm Cortex-M33 TZ MCU 100 MHz with 2 Mbytes of Flash memory, Bluetooth LE 6.0, 802.15.4, Zigbee, Thread | Active | 2 | 6 | 3 | 1 | 5 | 4 | 2 | 48 | 2 | 2 | Single-precision FPU | - | - | 1 | SAI | - | - | - | 8 | - | 1 | UFQFPN 48 7x7x0.55 mm | Arm Cortex-M33 | 100 | 2048 | 512 | 20 | 6 | 1
STM32WBA63CIU7 (https://www.st.com/en/product/stm32wba63ciu7.html) | Ultra-low-power, Arm Cortex-M33 TZ MCU 100 MHz with 2 Mbytes of Flash memory, Bluetooth LE 6.0, 802.15.4, Zigbee, Thread | Active | 2 | 6 | 3 | 1 | 5 | 4 | 2 | 48 | 2 | 2 | Single-precision FPU | - | - | 1 | SAI | - | - | - | 8 | - | 1 | UFQFPN 48 7x7x0.55 mm | Arm Cortex-M33 | 100 | 2048 | 512 | 20 | 6 | 1
STM32WBA63CIU6 (https://www.st.com/en/product/stm32wba63ciu6.html) | Ultra-low-power, Arm Cortex-M33 TZ MCU 100 MHz with 2 Mbytes of Flash memory, Bluetooth LE 6.0, 802.15.4, Zigbee, Thread | Active | 2 | 6 | 3 | 1 | 5 | 4 | 2 | 48 | 2 | 2 | Single-precision FPU | - | - | 1 | SAI | - | - | - | 8 | - | 1 | UFQFPN 48 7x7x0.55 mm | Arm Cortex-M33 | 100 | 2048 | 512 | 20 | 6 | 1
STM32WBA63CIU6TR (https://www.st.com/en/product/stm32wba63ciu6tr.html) | Ultra-low-power, Arm Cortex-M33 TZ MCU 100 MHz with 2 Mbytes of Flash memory, Bluetooth LE 6.0, 802.15.4, Zigbee, Thread | Active | 2 | 6 | 3 | 1 | 5 | 4 | 2 | 48 | 2 | 2 | Single-precision FPU | - | - | 1 | SAI | - | - | - | 8 | - | 1 | UFQFPN 48 7x7x0.55 mm | Arm Cortex-M33 | 100 | 2048 | 512 | 20 | 6 | 1
STM32L4Q5CGT6 (https://www.st.com/en/product/stm32l4q5cgt6.html) | Ultra-low-power with FPU Arm Cortex-M4 MCU 120 MHz with 1024 kbytes of Flash memory, USB OTG, DFSDM, CHROM-ART, AES, PKA | Active | - | 1 | - | 2 | 11 | - | - | 48 | 4 | 4 | Single-precision FPU | - | - | - | DFSDM, SAI | - | - | - | - | - | 2 | LQFP 48 7x7x1.4 mm | Arm Cortex-M4 | 120 | 1024 | 320 | 38 | 13 | 2
STM32L4Q5CGT6P (https://www.st.com/en/product/stm32l4q5cgt6p.html) | Ultra-low-power with FPU Arm Cortex-M4 MCU 120 MHz with 1024 kbytes of Flash memory, USB OTG, DFSDM, CHROM-ART, AES, PKA | Active | - | 1 | - | 2 | 11 | - | - | 48 | 4 | 4 | Single-precision FPU | - | - | - | DFSDM, SAI | - | - | - | - | - | 2 | LQFP 48 7x7x1.4 mm | Arm Cortex-M4 | 120 | 1024 | 320 | - | 13 | 2
STM32L4Q5CGU6 (https://www.st.com/en/product/stm32l4q5cgu6.html) | Ultra-low-power with FPU Arm Cortex-M4 MCU 120 MHz with 1024 kbytes of Flash memory, USB OTG, DFSDM, CHROM-ART, AES, PKA | Active | - | 1 | - | 2 | 11 | - | - | 48 | 4 | 4 | Single-precision FPU | - | - | - | DFSDM, SAI | - | - | - | - | - | 2 | UFQFPN 48 7x7x0.55 mm | Arm Cortex-M4 | 120 | 1024 | 320 | 38 | 13 | 2
STM32L4Q5CGU6P (https://www.st.com/en/product/stm32l4q5cgu6p.html) | Ultra-low-power with FPU Arm Cortex-M4 MCU 120 MHz with 1024 kbytes of Flash memory, USB OTG, DFSDM, CHROM-ART, AES, PKA | Active | - | 1 | - | 2 | 11 | - | - | 48 | 4 | 4 | Single-precision FPU | - | - | - | DFSDM, SAI | - | - | - | - | - | 2 | UFQFPN 48 7x7x0.55 mm | Arm Cortex-M4 | 120 | 1024 | 320 | - | 13 | 2
STM32L4P5CGT6 (https://www.st.com/en/product/stm32l4p5cgt6.html) | Ultra-low-power with FPU Arm Cortex-M4 MCU 120 MHz with 1024 kbytes of Flash memory, USB OTG, DFSDM, CHROM-ART | Active | - | 1 | - | 2 | 11 | - | - | 48 | 4 | 4 | Single-precision FPU | - | - | - | DFSDM, SAI | - | - | - | - | - | 2 | LQFP 48 7x7x1.4 mm | Arm Cortex-M4 | 120 | 1024 | 320 | 38 | 13 | 2
STM32L4P5CGU6 (https://www.st.com/en/product/stm32l4p5cgu6.html) | Ultra-low-power with FPU Arm Cortex-M4 MCU 120 MHz with 1024 kbytes of Flash memory, USB OTG, DFSDM, CHROM-ART | Active | - | 1 | - | 2 | 11 | - | - | 48 | 4 | 4 | Single-precision FPU | - | - | - | DFSDM, SAI | - | - | - | - | - | 2 | UFQFPN 48 7x7x0.55 mm | Arm Cortex-M4 | 120 | 1024 | 320 | 38 | 13 | 2
STM32L4P5CGT6P (https://www.st.com/en/product/stm32l4p5cgt6p.html) | Ultra-low-power with FPU Arm Cortex-M4 MCU 120 MHz with 1024 kbytes of Flash memory, USB OTG, DFSDM, CHROM-ART | Active | - | 1 | - | 2 | 11 | - | - | 48 | 4 | 4 | Single-precision FPU | - | - | - | DFSDM, SAI | - | - | - | - | - | 2 | LQFP 48 7x7x1.4 mm | Arm Cortex-M4 | 120 | 1024 | 320 | 38 | 13 | 2
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

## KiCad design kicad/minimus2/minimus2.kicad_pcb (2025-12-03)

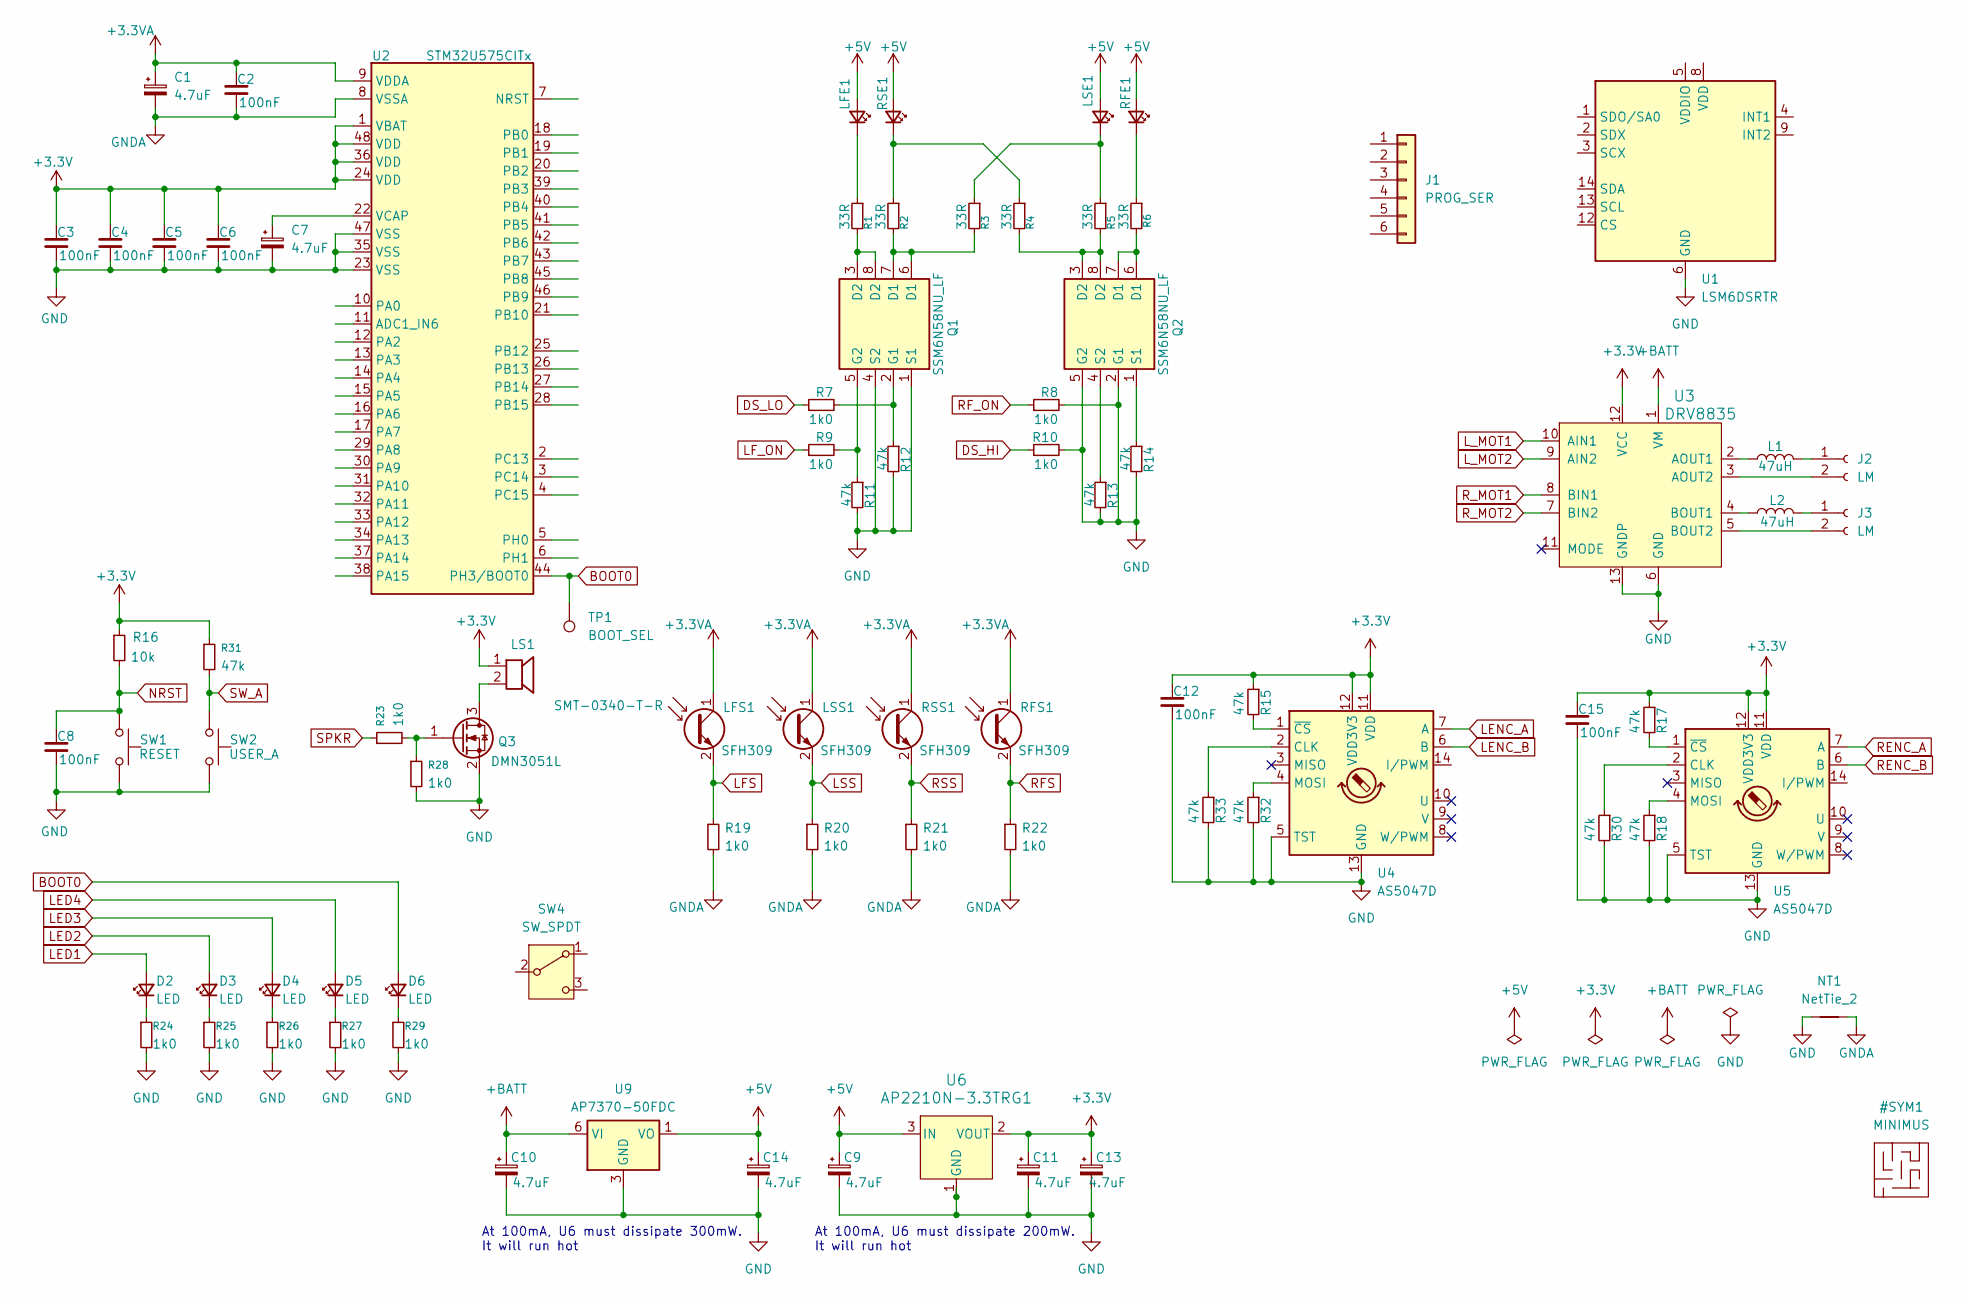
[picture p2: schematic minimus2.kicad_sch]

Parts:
C1, C7, C9, C10, C11, C13, C14: 4.7uF; C_0805_2012Metric
C2, C3, C4, C5, C6, C8, C12, C15: 100nF; C_0402_1005Metric
D2, D3, D4, D5, D6: LED; LED_0402_1005Metric
J1: PROG_SER; PinHeader_2x03_P1.27mm_Vertical
J2, J3: LM; PinHeader_1x02_P2.00mm_Vertical
L1, L2: 47uH; IFSC-1515AH-01
LFE1: SFH4050; LED_D3.0mm_Horizontal_O3.81mm_Z6.0mm
LFS1: SFH309; LED_D3.0mm_Horizontal_O1.27mm_Z2.0mm_Clear
LS1: SMT-0340-T-R; LCSC C3811754
LSE1: SFH4050; LED_D3.0mm_Horizontal_O3.81mm_Z6.0mm
LSS1: SFH309; LED_D3.0mm_Horizontal_O1.27mm_Z2.0mm_Clear
NT1: NetTie_2; NetTie-2_SMD_Pad0.5mm
Q1, Q2: SSM6N58NU_LF; SON65P200X200X80-8N; LCSC C262142
Q3: DMN3051L; SOT-23; LCSC C155348
R1, R2, R3, R4, R5, R6: 33R; R_0402_1005Metric
R7, R8, R9, R10, R19, R20, R21, R22, R23, R24, R25, R26, R27, R28, R29: 1k0; R_0402_1005Metric
R11, R12, R13, R14, R15, R17, R18, R30, R31, R32, R33: 47k; R_0402_1005Metric
R16: 10k; R_0402_1005Metric
RFE1: SFH4050; LED_D3.0mm_Horizontal_O3.81mm_Z6.0mm
RFS1: SFH309; LED_D3.0mm_Horizontal_O1.27mm_Z2.0mm_Clear
RSE1: SFH4050; LED_D3.0mm_Horizontal_O3.81mm_Z6.0mm
RSS1: SFH309; LED_D3.0mm_Horizontal_O1.27mm_Z2.0mm_Clear
SW1: RESET; SW_Push_1P1T_NO_CK_KMR2
SW2: USER_A; SW_Push_1P1T_NO_CK_KMR2
SW4: SW_SPDT; CUS-12TB_NDC
TP1: BOOT_SEL; TestPoint_Pad_D1.0mm
U1: LSM6DSRTR; LGA-14_3x2.5mm_P0.5mm_LayoutBorder3x4y; LCSC C784817
U2: STM32U575CITx; LQFP-48_7x7mm_P0.5mm
U3: DRV8835; LCSC C2848981
U4, U5: AS5047D; TSSOP-14_4.4x5mm_P0.65mm
U6: AP2210N-3.3TRG1; AP2210N-x.xTRG1_DIO
U9: AP7370-50FDC; DFN-6-1EP_2x2mm_P0.65mm_EP1.01x1.7mm; LCSC C6125709

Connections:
+3.3V: C3.1, C4.1, C5.1, C6.1, C11.1, C12.1, C13.1, C15.1, LS1.1, R15.1, R16.1, R17.1, R31.1, U2.1 (VBAT), U2.24 (VDD), U2.36 (VDD), U2.48 (VDD), U3.12 (VCC), U4.11 (VDD), U4.12 (VDD3V3), U5.11 (VDD), U5.12 (VDD3V3), U6.2 (VOUT)
+3.3VA: C1.1, C2.1, LFS1.1 (C), LSS1.1 (C), RFS1.1 (C), RSS1.1 (C), U2.9 (VDDA)
+5V: C9.1, C14.1, LFE1.2 (A), LSE1.2 (A), RFE1.2 (A), RSE1.2 (A), U6.3 (IN), U9.1 (VO)
+BATT: C10.1, U3.1 (VM), U9.6 (VI)
BOOT0: D6.2 (A), TP1.1, U2.44 (PH3/BOOT0)
DS_HI: R10.1
DS_LO: R7.1
GND: C3.2, C4.2, C5.2, C6.2, C7.2, C8.2, C9.2, C10.2, C11.2, C12.2, C13.2, C14.2, C15.2, NT1.1, Q1.1 (S1), Q1.4 (S2), Q2.2 (G1), Q2.5 (G2), Q3.2 (S), R8.2, R10.2, R11.2, R12.2, R13.2, R14.2, R18.2, R24.2, R25.2, R26.2, R27.2, R28.2, R29.2, R30.2, R32.2, R33.2, SW1.1, SW2.1, U1.6 (GND), U1.7 (GND), U2.23 (VSS), U2.35 (VSS), U2.47 (VSS), U3.6 (GND), U3.13 (GNDP), U4.5 (TST), U4.13 (GND), U5.5 (TST), U5.13 (GND), U6.1 (GND), U9.3 (GND), U9.7 (GND)
GNDA: C1.2, C2.2, NT1.2, R19.2, R20.2, R21.2, R22.2, U2.8 (VSSA)
LED1: D2.2 (A)
LED2: D3.2 (A)
LED3: D4.2 (A)
LED4: D5.2 (A)
LENC_A: U4.7 (A)
LENC_B: U4.6 (B)
LFS: LFS1.2 (E), R19.1
LF_ON: R9.1
LSS: LSS1.2 (E), R20.1
L_MOT1: U3.10 (AIN1)
L_MOT2: U3.9 (AIN2)
NRST: C8.1, R16.2, SW1.2
unnamed: D2.1 (K), R24.1
unnamed: D3.1 (K), R25.1
unnamed: D4.1 (K), R26.1
unnamed: D5.1 (K), R27.1
unnamed: D6.1 (K), R29.1
unnamed: J2.1, L1.2
unnamed: J2.2, U3.3 (AOUT2)
unnamed: J3.1, L2.2
unnamed: J3.2, U3.5 (BOUT2)
unnamed: LFE1.1 (K), R1.1
unnamed: LSE1.1 (K), R3.1, R5.1
unnamed: Q1.6 (D1), Q1.7 (D1), R2.2, R3.2
unnamed: Q1.3 (D2), Q1.8 (D2), R1.2
unnamed: Q1.2 (G1), R7.2, R12.1
unnamed: Q1.5 (G2), R9.2, R11.1
unnamed: Q2.6 (D1), Q2.7 (D1), R6.2
unnamed: Q2.3 (D2), Q2.8 (D2), R4.2, R5.2
unnamed: Q2.1 (S1), R14.1
unnamed: Q2.4 (S2), R13.1
unnamed: LS1.2, Q3.3 (D)
unnamed: Q3.1 (G), R23.2, R28.1
unnamed: R6.1, RFE1.1 (K)
unnamed: R2.1, R4.1, RSE1.1 (K)
unnamed: C7.1, U2.22 (VCAP)
unnamed: L1.1, U3.2 (AOUT1)
unnamed: L2.1, U3.4 (BOUT1)
unnamed: R33.1, U4.2 (CLK)
unnamed: R32.1, U4.4 (MOSI)
unnamed: R15.2, U4.1 (~CS)
unnamed: R30.1, U5.2 (CLK)
unnamed: R18.1, U5.4 (MOSI)
unnamed: R17.2, U5.1 (~CS)
RENC_A: U5.7 (A)
RENC_B: U5.6 (B)
RFS: R22.1, RFS1.2 (E)
RF_ON: R8.1
RSS: R21.1, RSS1.2 (E)
R_MOT1: U3.8 (BIN1)
R_MOT2: U3.7 (BIN2)
SPKR: R23.1
SW_A: R31.2, SW2.2

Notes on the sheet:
At 100mA, U6 must dissipate 200mW. It will run hot
At 100mA, U6 must dissipate 300mW. It will run hot

Board: 2 copper layers, 82 parts (0 on the bottom side), 45 nets, no tracks yet.

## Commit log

2025-10-28 add some skeleton kicad files
    [minimus2.kicad_pcb, minimus2.kicad_sch]
2025-10-28 add some stm32f413 files
    [stm32f413_af.csv]
2025-10-31 add STM32U575/585 docs
2025-10-31 add to kicad project
    [minimus2.kicad_pcb, minimus2.kicad_sch]
2025-10-31 add some data files
    [stm32-product-selector.xlsx]
2025-11-27 add motor mount models
2025-11-27 update the footprints
2025-11-27 update PCB with motors
    [minimus2.kicad_pcb, minimus2.kicad_sch]
2025-11-27 add datasheet for AP7370 LDO regulator
2025-11-27 add footprint for AP7370 regulator
2025-11-27 update power supply
    [minimus2.kicad_pcb, minimus2.kicad_sch]
2025-11-27 add a regulator datasheet
2025-11-27 extend the mouse by 5mm to rear
    [minimus2.kicad_pcb]
2025-11-29 update EDA
    [minimus2.kicad_pcb, minimus2.kicad_sch]
2025-11-29 simplifythe processor pinout table
    [stm32u585_af.csv]
2025-11-29 add revised thin motor mounts
2025-11-29 update the motor mount footprints
2025-11-29 update the motor mounts
    [minimus2.kicad_pcb]
2025-11-29 add guideline graduations to silkscreen
    [minimus2.kicad_pcb]
2025-11-29 populate the encoder carriers
    [minimus2.kicad_pcb]
2025-12-03 add drivetrain sketch
2025-12-03 update encoder board size
    [minimus2.kicad_pcb]
